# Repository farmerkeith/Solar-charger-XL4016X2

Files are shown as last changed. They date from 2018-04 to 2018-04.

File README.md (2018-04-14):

# Solar-charger-XL4016X2
MPPT Solar charger based on a design by zopinter 
This design uses two commercial DC-DC converter modules based on XL4016, and Arduino Nano for control.
It also has a supplementary input from mains supply controlled from the Nano, and a controlled Load output.
Reverse current flow to the XL4016 converter modules and to the mains supply is prevented by "MOSFET diodes" each consisting of an IRF4905 MOSFET controlled by two BJTs. 
Current flow to and from the battery is monitored, in addition to the solar panel voltage and current and battery voltage essential to the operation of the MPPT algorithm.

# Peripherals
Battery temperature is monitored with a DS18B20 sensor and used to adjust battery set points.
Operational data logging is provided by a micro SD card, with time stamps from a Tiny RTC module using a DS1307 IC. 
An LCD character display provides status information. A push button turns on the backlight of the LCD, saving power when the LCD is not required to be on. 

# Schematic
The schematic circuit diagram has been prepared using KiCad. 

# Layout
A possible layout of the components using Fritzing can be found in the Layout folder. The schematic and PCB parts of the Fritzing files have not been made useful. 

# Software
The software for the Arduino Nano (C++ code) is in the software folder. It still requires change for (at least):
 - pin allocations to correspond to hardware
 - deal with two rather than one XL4016 module
 - data logging and clock
 - testing

See the software code for a full listing of Arduino Nano pin allocations.

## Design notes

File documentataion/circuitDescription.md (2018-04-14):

# Circuit description

Reference: KiCad schematic XL4016X2Single. This is the complete schematic on a single A4 sheet.

# Solar charger circuit
Starting at the top left corner is J1 labelled Solar Panel. The positive and negative wires from the solar panel connect here.

The first component is D3 P6KE47CA which is a transient suppressor diode. Its breakdown voltage is 47 volts. Its purpose is to protect the charger from things like lightning strikes.

Next you find resistors R1, R3 and capacitor C1 (it should be a different label; I will need to change it). The resistors divide the panel voltage down to a level compatible with the Arduino nano, and connect to Arduino pin A0 which does voltage measurement. The voltage range is 5 volts (Arduino Vcc) * (100+15)/15 = 38 Volts, which is enough for a 60-cell solar panel which has an open circuit voltage of 37.8 Volts.

Next you find U2 which is an ACS712 module. It is a Hall effect current sensor. The current from the panel flows in on the P- terminals and out on the P+ terminals. The amount of current affects the voltage on the OUT pin (at the bottom of the module). With zero current the OUT pin sits at Vcc/2, nominally 2.5 Volts. The OUT pin is connected to Arduino A1, which gives a digital measurement of that voltage, and is translated in the software to a current in Amps or milliAmps. The sensitivity of the "5 Amp" module I have specified here is 185 mV per amp, so it can easily measure the maximum current from the solar panel which is 8.7 Amps.

After U2 you find four capacitors C1.1 to C1.4 in parallel. They are there to smooth the current from the panel (which needs to be steady) to the buck converters (which will be of an impulsive nature).

The buck converters U1 and U3 do a DC-DC conversion function. At their output, each converter is rated for 8 Amps, and current limited by internal circuitry to 10 Amps approximately. To achieve good utilisation of your solar panel capacity requires two of these modules added together. They work in parallel. If your panel is at its maximum power point of 31.5 Volts, and the battery is being charged at 12.0 volts with a current of 20 Amps, 10 amps for each of U1 and U3, the input current will be a total of 20*12/31.5=7.6 Amps, or 3.8 Amps per module.  Each of the converters U1 and U3 also has its own smoothing capacitors at the input. I have shown C1.1 to C1.4 because there is a lot of heat generated in these capacitors and putting in some extras is not very expensive and reduces the heating and shoule improve the life time.

The conversion ratio of the two converters U1 and U3 is controlled by PWM signals from the Arduino using pins D9 and D10.

Next is the two MOSFET diode circuits, one for each converter, which then connect the current to the battery via the second ACS712, U4. The main component in each of the two MOSFET diode circuits is the MOSFET, that is Q1 for DC module U1, and Q6 for DC module U3.

The second ACS712 (U4) measures the current both into and out of the battery. Typical situations are current in from the solar panel, and current out to the load. When the mains supply is turned on, it will either decrease the current drawn by the load, or add to the current provided by the solar panels. 

Just to the right of module U4 is the voltage divider for measuring the battery voltage, consisting of resistors R12 and R16 and capacitor C2. The voltage range is 5 volts (Arduino Vcc) * (100+47)/47 = 15.6 Volts, which is enough for a 12 volt lead acid battery. 

Further to the right again is a MP2307 DC-Dc module which draws power from the battery and delivers +5 volts to all the electronic circuits  that require it. 

The last element before the battery connector is a fuse which is there to prevent accidental short circuits causing major component failure. 

# Load control circuit

The load control circuit is in the top right corner of the schematic. It consists of an IRF4905 P-channel MOSFET controlled via a transistor from Arduino pin D4. Pin D4 should be High to turn the load ON, and Low to turn it Off. 

# Mains supply circuit

Mains power comes from a commercial mains adaptor with an output of 12 volts at up to 3 Amps. The adapter is connected via barrel jack J9 which provides a 5.5mm coaxial connection commonly used for mains adapters. These adapters can be sensitive to being fed voltage into them when there is no mains power applied, hence there is a MOSFET diode to prevent that (main component Q9). Mains can be connected or disconnected by Q10 which is controlled via a transistor from Arduino pin D3. 

# Temperature measuring

Battery temperature is measured using DS18B20 U7, connected via a cable through screw terminal J8.

Temperature of the controller is measured using DS18B20 U11 mounted on the TinyRTC real time clock module. 

# Real Time Clock 

In order to be able to accurately time stamp the logged data, a real time clock module is used with a DS1307 and crystal oscillator. The accuracy should be sufficient for this purpose. 

This particular module is also equipped with an EEPROM with 4 kbytes capacity which enables the storage of logging data while the SD card is being unloaded from time to time.

Both the clock and the EEPROM are accessed via the I2C interface from Arduino pins A4 and A5.

# Micro SD card

Data logging is done to a micro SD card which provides ample storage capability for several years of data. Data will be recorded in comma separated text files. Details of the data required and the file duration is to be decided. 

# LCD display

The LCD display will show operational parameters, such as current, voltage and power for the solar panel and the battery, and the operating mode (solar charging; load on or off; mains on or off) 

To see the charactrs in the LCD screen, its back light needs to be turned on. However the back light consumes some power, which is a waste when nobody is there to look at it. Hence we provide a button, so that when somebody wants to see the LCD, they can press the button, and the back light will come on for a set period of time, and then go off again. The time period will be in the software, it could be 15 seconds or a minute, something like that.

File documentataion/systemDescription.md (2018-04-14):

# System Description
# Main functions:
1. Receive energy from a solar panel at a voltage of about 30V and transfer it to a battery at about 12V. 
2. Supply power from the battery to a load consiston of LED floodlights. The LED floodlights should come on when it gets dark in the evening, and turn off either when the next day starts, or if the battery reaches a threshold voltage indicating it has been discharged sufficiently so that further discharge may cause damage. 
3. Switch on a mains supply input at a time close to the end of the day if the battery has not been sufficiently charged during the day as indicated by the charge voltage not reaching a threshold (mains connect threshold). Keep the mains supply connected until the battery reaches a mains disconnect threshold.
4. Perform management of the battery so that it can reach its maximum useful life. This involves: a) boost charge of up to 1 hour per day; b) float charge for the remainder of the day; c) load disconnect threshold to stop further discharge; d) load reconnect threshold to allow reconnection of the load; e) adjustment of voltage thresholds according to the battery temperature.
5. Self protection against transient voltage surges from the solar panel input.
6. Overload protection against excessive temperature.

# Peripheral functions:
7. LCD display of operating values and status (voltages, currents, connections).
8. Data logging of operating values and status to an SD card, with predefined file structure (day files or week files or month files or several?)
9. Real time clock to provide a time stamp to logged data.

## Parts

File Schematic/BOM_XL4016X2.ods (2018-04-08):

 | Bill of Materials for XL4016X2 solar charger project
Sort code | Component | Reference | Value | Cost
1 | Capacitor Electrolytic | C1.1 | 100uF | $0.50
1 | Capacitor Electrolytic | C1.2 | 100uF | $0.50
1 | Capacitor Electrolytic | C1.3 | 100uF | $0.50
1 | Capacitor Electrolytic | C1.4 | 100uF | $0.50
1 | Capacitor Electrolytic | C4 | 10uF | $0.10
2 | Capacitor bypass | C2 | 100nF | $0.10
2 | Capacitor bypass | C3 | 100nF | $0.10
3 | Diode | D1 | 1N4148 | $0.10
3 | Diode | D2 | 1N4148 | $0.10
3 | Diode | D3 | 1N4148 | $0.10
3 | Diode | D4 | 1N4148 | $0.10
3 | Diode | D5 | 1N4148 | $0.10
3 | Diode | D6 | 1N4148 | $0.10
3 | Diode | D7 | 1N4148 | $0.10
3 | Diode | D8 | 1N4148 | $0.10
4 | TVS Diode | D9 | P6KE47CA | $0.10
5 | Fuse | F1 | Fuse_20A | $1.00
6 | Screw terminal 2 | J1 | Solar panel | $0.20
6 | Screw terminal 2 | J2 | Battery | $0.20
6 | Screw terminal 2 | J3 | LOAD | $0.20
6 | Screw terminal 2 | J5 | Buck1_IN | $0.20
6 | Screw terminal 2 | J6 | Buck1_OUT | $0.20
6 | Screw terminal 2 | J7 | Buck2_IN | $0.20
6 | Screw terminal 2 | J8 | Buck2_OUT | $0.20
6 | Screw terminal 3 | J4 | Temperature | $0.30
7 | MOSFET | Q1 | IRF4905 | $0.60
7 | MOSFET | Q12 | IRF4905 | $0.60
7 | MOSFET | Q3 | IRF4905 | $0.60
7 | MOSFET | Q6 | IRF4905 | $0.60
7 | MOSFET | Q9 | IRF4905 | $0.60
8 | BJT NPN | Q13 | 2N3904 | $0.05
8 | BJT NPN | Q2 | 2N3904 | $0.05
8 | BJT PNP | Q10 | 2N3906 | $0.05
8 | BJT PNP | Q11 | 2N3906 | $0.05
8 | BJT PNP | Q4 | 2N3906 | $0.05
8 | BJT PNP | Q5 | 2N3906 | $0.05
8 | BJT PNP | Q7 | 2N3906 | $0.05
8 | BJT PNP | Q8 | 2N3906 | $0.05
10 | Temperature sensor | U5 | DS18B20 | $2.00
11 | Module | U1 | ACS712module | $1.00
11 | Module | U2 | ACS712module | $1.00
11 | Module | U3 | XL4016_DC-DC_module | $5.00
11 | Module | U4 | XL4016_DC-DC_module | $5.00
11 | Module | U6 | ArduinoNano | $4.00
11 | Module | U7 | ESP-01 | $1.50
11 | Module | U9 | MP2307_DC-DC_module | $1.00
11 | Voltage Regulator | U8 | AMS1117-33 | $0.20
12 | Pushbutton | SW1 | Backlight control | $0.10
12 | Display | U10 | LCDSerial2004 | $6.00
21 | Resistor | R16 | 1K | $0.01
21 | Resistor | R13 | 2K2 | $0.01
21 | Resistor | R14 | 2K2 | $0.01
21 | Resistor | R15 | 2K2 | $0.01
22 | Resistor | R19 | 4K7 | $0.01
23 | Resistor | R11 | 10K | $0.01
23 | Resistor | R18 | 10K | $0.01
23 | Resistor | R20 | 10K | $0.01
24 | Resistor | R2 | 15K | $0.01
25 | Resistor | R3 | 22K | $0.01
25 | Resistor | R5 | 22K | $0.01
25 | Resistor | R9 | 22K | $0.01
26 | Resistor | R6 | 47K | $0.01
26 | Resistor | R10 | 47K | $0.01
26 | Resistor | R12 | 47K | $0.01
26 | Resistor | R4 | 47K | $0.01
27 | Resistor | R1 | 100K | $0.01
27 | Resistor | R17 | 100K | $0.01
27 | Resistor | R7 | 100K | $0.01
27 | Resistor | R8 | 100K | $0.01
40 | Wire & hardware
50 | Prototype circuit board |  |  | 2
101 | Barrel jack |  |  | 1
101 | Battery | BT1 | Battery_FLA_+12V_120AH
102 | Mains power converter 12V 3A |  |  | 35
103 | Enclosure
 | Total |  |  | $74.30

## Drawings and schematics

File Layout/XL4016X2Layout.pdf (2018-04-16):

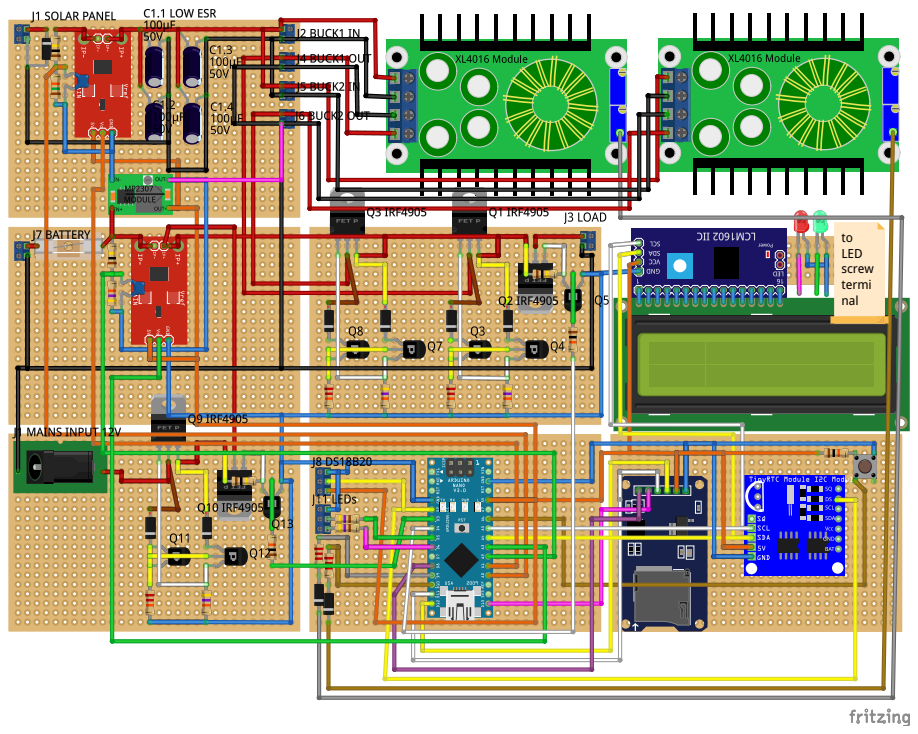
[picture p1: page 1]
to LED screw termi nal

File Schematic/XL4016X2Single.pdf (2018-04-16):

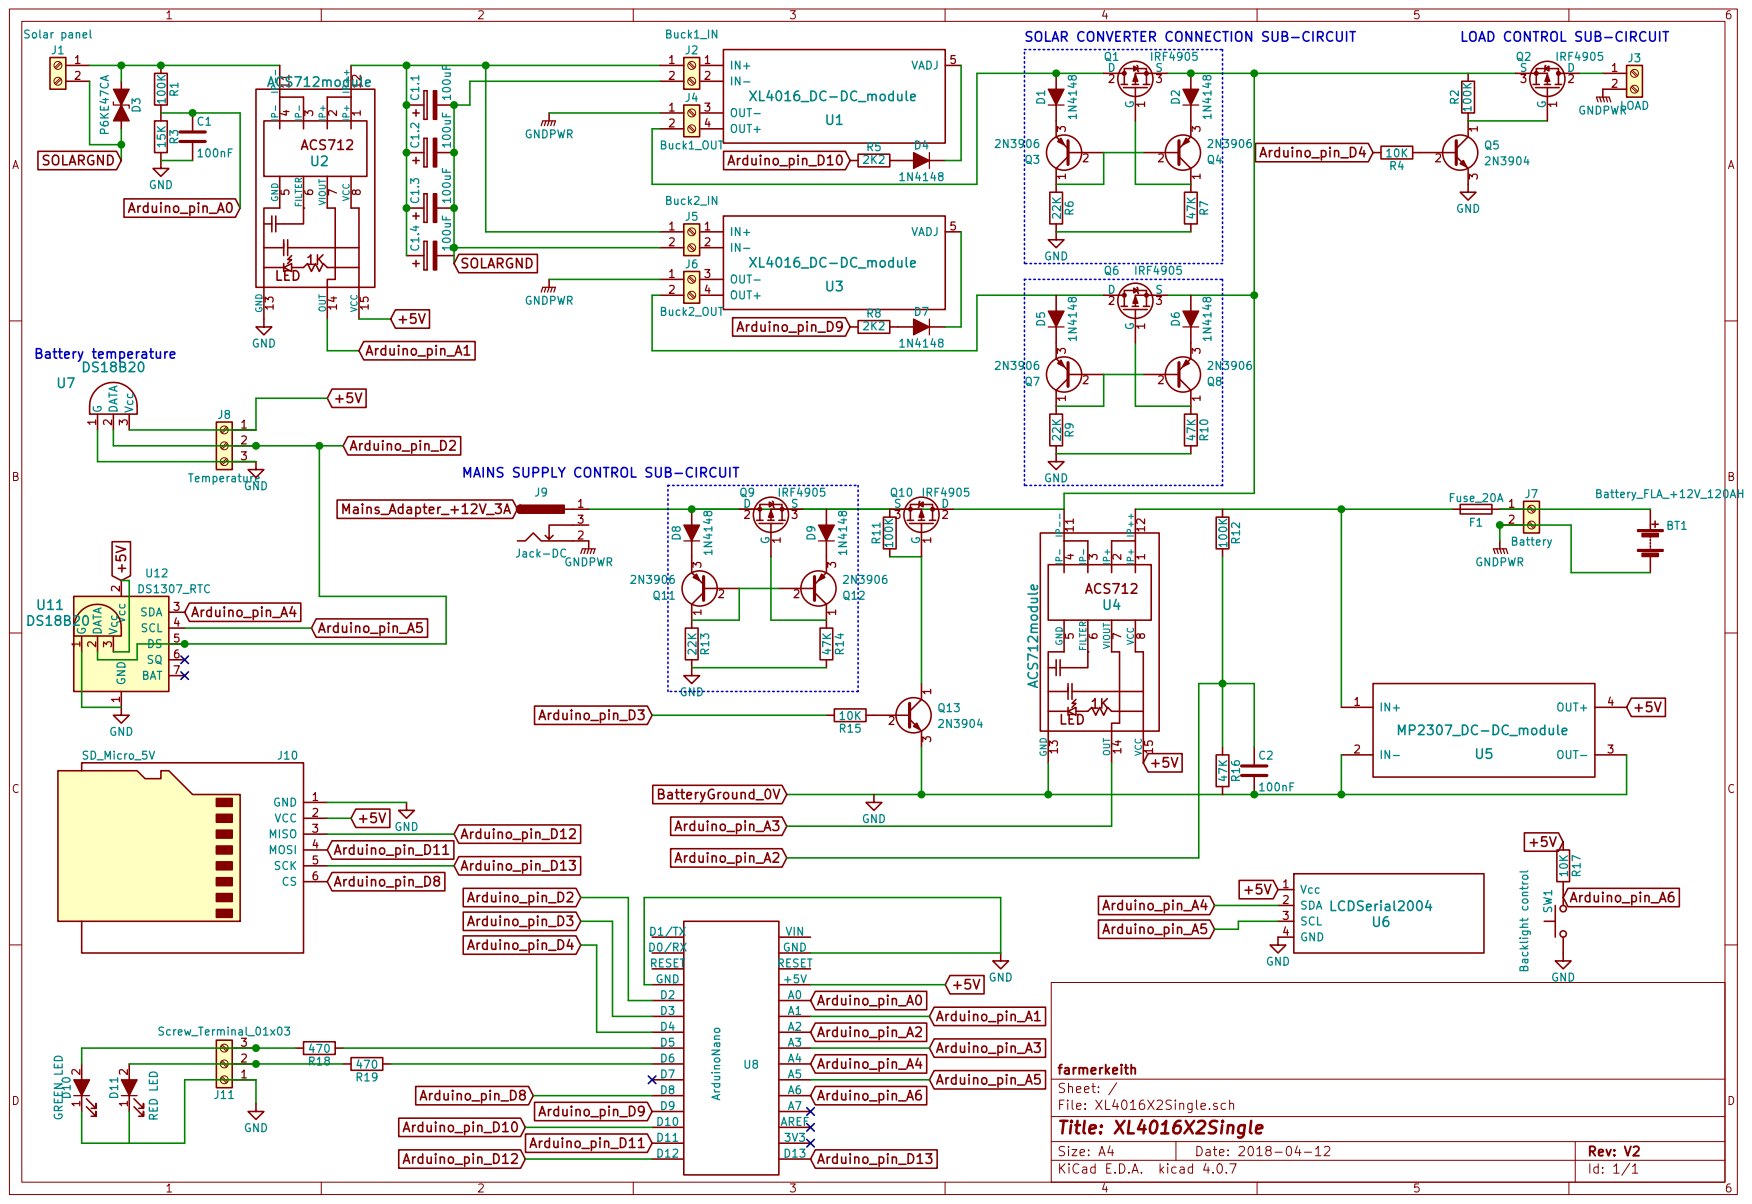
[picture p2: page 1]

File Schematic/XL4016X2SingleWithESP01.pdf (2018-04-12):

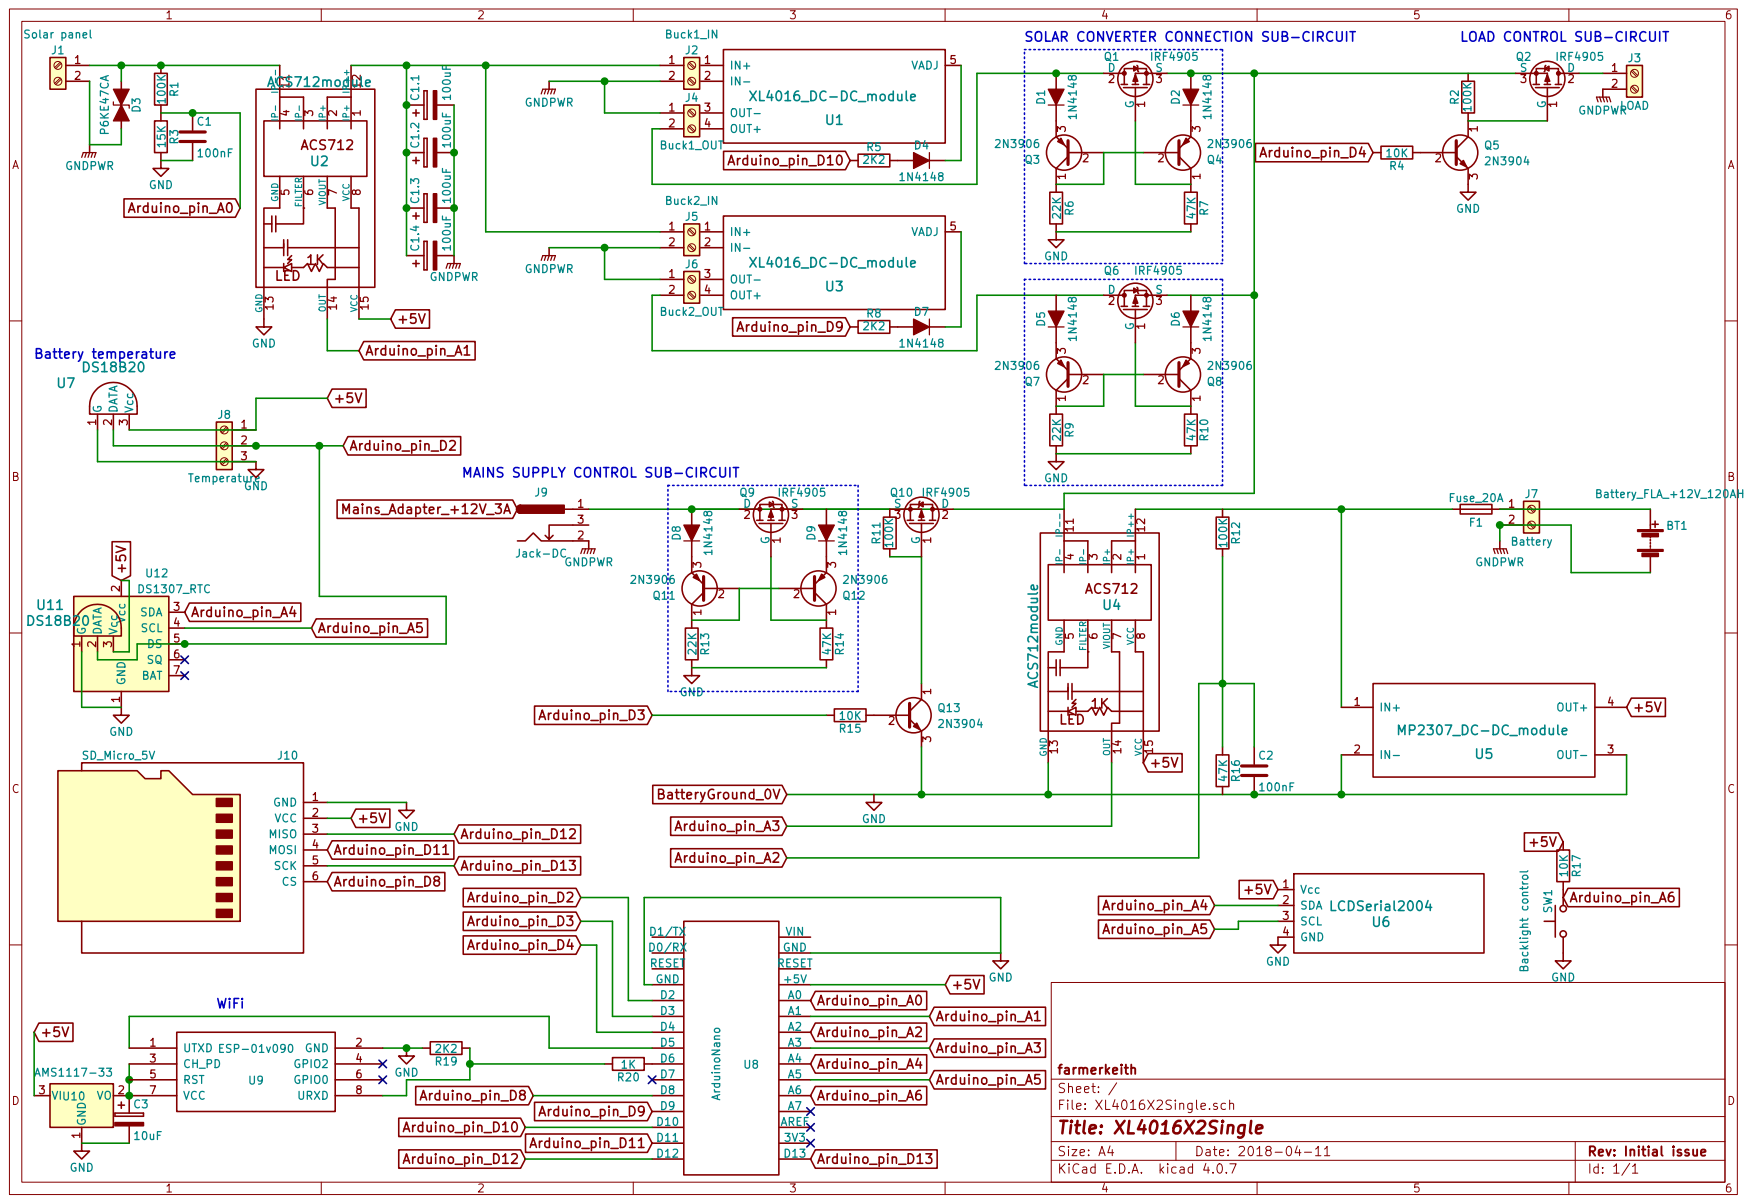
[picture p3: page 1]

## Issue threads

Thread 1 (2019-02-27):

Documentation and working of project

athulsnair, 2019-02-27:
Hello,

      This is not an issue, but I'm interested in doing this project. Where can I find necessary documentation and part list, schematics??

Thanks

farmerkeith, 2019-02-27:
All the documentation that exists can be found under the "code" tab - schematic and some limited documentation.
Depending on your needs, you may find the design using SZBK07 more valuable.
Please also see my Instructable on Controlling DC converter modules for more in-depth information.
https://www.instructables.com/id/Controlling-DC-Converter-Modules/
Keith

Closed 2019-02-27.

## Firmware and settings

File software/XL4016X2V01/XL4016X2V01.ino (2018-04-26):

// software for XL4016X2 solar charger 
// Modified by farmerkeith
// based on version by zopinter
// based on MPPT solar charger Version 3 by deba168
// based on work by Tim Nolan
// modification commenced 13 April 2018
// last change 23 April 2018

// key components:
// Arduino Nano V3 microcontroller
// 2 DC-DC converter modules based on XL4016 with pwm control of output voltage via feedback pin
// XL4016 controlled by the Nano (pwm on D9 and D10)
// solar panel up to 240W Voc<39V Isc<8 Amps
// AGM or flooded lead acid battery nominal 12V
// mains power charge supplement controlled by the Nano (D3)
// LED night time lighting load controlled by the Nano (D4)
// Battery temperature monitored by DS18B20 and used to adjust battery set points (D2)
// LCD display of operational data (I2C on A4, A5)
// LCD backlight controlled by a momentary action push button (A6)
// Micro SD card for data logging (SPI on D11, D12, D13 with CS on D8)
// TinyRTC DC1307 real time clock (I2C on A4, A5)
// Solar controller temperature monitored by DS18B20 mounted on RTC (D2)
// Battery current in and out monitored by ACS712 20A (A3)
// Red and Green status indicators (D5, D6). 

// 2017.01.01: 14938KWh
// Adding HTU21DF sensor
// Adding separate voide for MPPT PO and IC algorith
// Adding EEPROM store
//----------------------------------------------------------------------------------------------------

//////// Arduino pins Connections//////////////////////////////////////////////////////////////////////////////////
// A0 - Solar panel voltage 100K/15K divider
// A1 - Solar panel current ACS 712 5A
// A2 - Battery voltage 100K/47K divider
// A3 - Battery current ACS 712 5A 
// A4 - I2C SDA for LCD, RTC and EEPROM
// A5 - I2C SCL for LCD, RTC and EEPROM
// A6 - Pushbutton for LCD backlight control
// A7 - Spare - use if needed for cooling FAN control 

// D0 - reserved for USB to host
// D1 - reserved for USB to host
// D2 - DS18B20 * 2
// D3 - Mains power control
// D4 - Load control
// D5 - Green LED  
// D6 - Red LED 
// D7 - Spare 
// D8 - CS for SPI to micro SD card
// D9 - PWM control of XL4016 #2
// D10 - PWM control of XL4016 #1
// D11 - SPI MOSI
// D12 - SPI MISO
// D13 - SPI clock SCK; also Nano on board LED

// possible other functions
// COOLING FAN control
// AIR CLEANING FAN control
// ACS712 ENABLE/DISABLE ??

// include libraries ---------------------------------------------------------------------
#include <Wire.h>
#include <LiquidCrystal_I2C.h>
#include <AnalogSmooth.h>
// #include "Adafruit_HTU21DF.h"
#include <EEPROM.h>

// include tab files ---------------------------------------------------------------------
#include "data_recording.h"
#include "LCDcustom_characters.h"

//-----------------------------------------------------------------------------------------------------------------
///////// Hardware connection constants /////////////////////////////////////////////////////////////////////////////////////////////////
//#define BAT_FLOAT 12.35                  // battery voltage we want to stop charging at

const byte SOL_VOLTS_CHAN =0;               // defining the adc channel to read solar volts on A0
const byte SOL_AMPS_CHAN =1;                // Defining the adc channel to read solar amps on A1
const byte BAT_VOLTS_CHAN =2;               // defining the adc channel to read battery volts on A2
const byte BUCK_AMPS_CHAN =3;               // Defining the adc channel to read battery amps on A3
const byte BACK_LIGHT_PIN =6;               // pin A6 is used to control the lcd back light

const byte DS18B20_pin = 2;  // D2 for One-wire to DS18B20 * 2
const byte mains_pin = 3;    // D3 - Mains power control
const byte load_pin = 4;     // D4 - Load control
const byte greenLED_pin =5;  // D5 - Green LED  
const byte redLED_pin = 6;   // D6 - Red LED 
// D7 - Spare 
const byte sd_CS_pin =8;     // D8 - CS for SPI to micro SD card
const byte pwm_buck2 = 9;    // D9 - PWM control of XL4016 #2
const byte pwm_buck1 =10;    // D10 - PWM control of XL4016 #1
// #define PWM_PIN 11

// global constants ----------------------------------------------------------------------
#define wattHours_setup 5983
#define daily_wattHours_setup 0
#define ampHours_setup 0

// #define COOLING_FAN_PWM_PIN 3               // pin used to control air cleaning fan in room
// #define TURN_ON_COOLING_FAN analogWrite(COOLING_FAN_PWM_PIN, 55)
// #define TURN_OFF_COOLING_FAN analogWrite(COOLING_FAN_PWM_PIN, 0)

// #define NIGHT_LIGHT_ENABLE_PIN 7                                             // pin used to control night light
// #define TURN_ON_NIGHT_LIGHT digitalWrite(NIGHT_LIGHT_ENABLE_PIN, HIGH)      // enable Night light
// #define TURN_OFF_NIGHT_LIGHT digitalWrite(NIGHT_LIGHT_ENABLE_PIN, LOW)      // disable Night light

//#define BIG_FAN_PWM_PIN 9                       // pin used to control air cleaning fan in room
//#define TURN_OFF_BIG_FAN analogWrite(BIG_FAN_PWM_PIN, 0)

// #define ACS_ENABLE_PIN 10                                    // pin used to control ACS712 power for energy save purposes
// #define TURN_ON_ACS digitalWrite(ACS_ENABLE_PIN, HIGH)      // enable ACS712 sensors
// #define TURN_OFF_ACS digitalWrite(ACS_ENABLE_PIN, LOW)      // disable ACS712 sensors

#define LED_ON 50                            //milliseconds
#define LED_OFF 5000
unsigned long ms;                          //time from millis()
unsigned long msLast;                      //last time the LED changed state
boolean ledState;                          //current LED state

#define SOL_AMPS_SCALE  0.048828125        // ACS 712 Current Sensor is used. Current Measured = (5/(1024 *0.185))*ADC - (2.5/0.100)
#define BUCK_AMPS_SCALE 0.048828125        // the scaling value for raw adc reading to get solar amps   // 5/(1024*0.100)
#define SOL_VOLTS_SCALE 0.0299        // the scaling value for raw adc reading to get solar volts  // (5/1024)*(R1+R2)/R2 // R1=100k and R2=20k
#define BAT_VOLTS_SCALE 0.0299        // the scaling value for raw adc reading to get battery volts 
#define AVG_NUM 50                          // number of iterations of the adc routine to average the adc readings



//-------------------------------------------- Global variables --------------------------------------------------------
float sol_amps_previous = 0;
float sol_volts_previous = 0;
float buck_amps_previous = 0;


float sol_amps;                       // solar amps
float buck_amps;                      // solar amps

float sol_volts;                      // solar volts
float old_sol_volts = 0;

float bat_volts;                      // battery volts

float sol_watts;                      // solar watts

float buck_watts;                     // buck watts
float rbuck_watts;                    // rounded buck watts

float mppt_track;
float rmppt_track;
float old_mppt_track = 0;

//unsigned int seconds = 0;             // seconds from timer routine
//unsigned int prev_seconds = 0;        // seconds value from previous pass
//unsigned int interrupt_counter = 0;   // counter for 20us interrrupt

int fan_pwm = 0;
int bat_volts_map = 0;                 // for mapping bat volts to fan pwm
int night_light_state = 0;             // variable for storing the load output state (for writing to LCD)

int pwm_value = 0;
int trackDirection = 1;                // step amount to change the value of pulseWidth used by MPPT algorithm

unsigned long ms1 = 0;               // variable to store time the back light control button was pressed in millis
unsigned long ms2 = 0;               // variable to store time the back light control button was pressed in millis
unsigned long ms3 = 0;               // variable to store time the back light control button was pressed in millis
int back_light_pin_State = 0;         // variable for storing the state of the backlight button
int back_light_state = 0;

/*
  float gain;
  int gain_sum = 0;
  int gain_temp = 0;
  int gain_counter = 0;
*/

float eff;                             // efficiency
int eff_sum = 0;
int eff_temp = 0;
int eff_counter = 0;

enum charger_mode {SLEEP, MPPT, FLOAT} charger_state;  // enumerated variable that holds state for charger state machine

float max_sol_watts = 0;              // PZ added
float daily_max_sol_watts = 0;        // PZ added

float max_buck_amps = 0;              // PZ added
float daily_max_buck_amps = 0;        // PZ added

unsigned int msec = 0; // PZ added
int last_msec = 0; // PZ added
int elasped_msec = 0; // PZ added
float elasped_time = 0; // PZ added
float ampSecs = 0; // PZ added
float ampHours = 0; // PZ added
float wattSecs = 0; // PZ added
float wattHours_decimal; // PZ added
float wattHours_temp = 0; // PZ added
float daily_wattHours = 0;
unsigned long wattHours = 0;

LiquidCrystal_I2C lcd(0x27, 2, 1, 0, 4, 5, 6, 7, 3, POSITIVE);  // Set the LCD I2C address

// Adafruit_HTU21DF htu = Adafruit_HTU21DF();

//AnalogSmooth as = AnalogSmooth();
AnalogSmooth as100 = AnalogSmooth(50);


//------------------------------------------------------------------------------------------------------
// This routine is automatically called at powerup/reset
//------------------------------------------------------------------------------------------------------

void setup()                           // run once, when the sketch starts
{
  // recover data from EEPROM
  wattHours = wattHours_setup;
  //  start_wattHours = wattHours_setup;

  ampHours = ampHours_setup;
  daily_wattHours = daily_wattHours_setup;

  TCCR1B = TCCR1B & B11111000 | B00000001;    // set timer 1 (pin 9&10)divisor to 1 for PWM frequency of 31372.55 Hz
  // TCCR2B = TCCR2B & B11111000 | B00000101;    // set timer 2 (pin 3&11) divisor to 1 for PWM frequency of 240 Hz

  DIDR0 = 0x0F;  //Turn off digital input function on ADC channel 0-3, since we will use analogue signals

  Serial.begin(250000);

  pwm_value = 100;
  charger_state = FLOAT;               // start with charger state as sleep

  lcd.begin(20, 4);                    // initialize the lcd for 16 chars 2 lines, turn on backlight
  lcd.noBacklight();                   // turn off the backlight
  back_light_state = 0;
  lcd.createChar(1, solar);            // turn the bitmap into a character
  lcd.createChar(2, battery);          // turn the bitmap into a character
  lcd.createChar(3, _PWM);             // turn the bitmap into a character

//  pinMode(ACS_ENABLE_PIN, OUTPUT);     // sets the digital pin as output
//  TURN_ON_ACS;                         // turn off ACS712

//  pinMode(NIGHT_LIGHT_ENABLE_PIN, OUTPUT);           // output for the LOAD MOSFET (LOW = on, HIGH = off)
//  TURN_OFF_NIGHT_LIGHT;
//  night_light_state = 0;

//  pinMode(BIG_FAN_PWM_PIN, OUTPUT);           // output for the LOAD MOSFET (LOW = on, HIGH = off)

  pinMode (BACK_LIGHT_PIN, INPUT);

  pinMode (pwm_buck1, OUTPUT);
  pinMode (pwm_buck2, OUTPUT);

//  pinMode (COOLING_FAN_PWM_PIN, OUTPUT);

  pinMode(greenLED_pin, OUTPUT);          // sets the digital pin as output
  pinMode(redLED_pin, OUTPUT);            // sets the digital pin as output
}

//------------------------------------------------------------------------------------------------------
// Main loop
//------------------------------------------------------------------------------------------------------
void loop()
{
  read_data();                         // read data from inputs
  mode_select();                       // select the charging state
  set_charger();                       // run the charger state machine
  // print_data();                        // print data
  // cooling_fan();
  // big_fan();
  // night_light();
  // power_save(); // ACS712 uses 10mA at 5V
  keepalive_led();
  lcd_display();                       // lcd display
  // MPPT_test();
  others();                            // max watts and amps;
}

//------------------------------------------------------------------------------------------------------
// This routine reads and averages the analog inputs for this system, solar volts, solar amps and
// battery volts.
//------------------------------------------------------------------------------------------------------
unsigned int read_adc(int channel) {

  unsigned int sum = 0;
  unsigned int temp;
  int i;

  for (i = 0; i < AVG_NUM; i++) {      // loop through reading raw adc values AVG_NUM number of times
    temp = analogRead(channel);        // read the input pin
    sum += temp;                       // store sum for averaging
    delayMicroseconds(100);             // pauses for 50 microseconds
  }
  return (sum / AVG_NUM);              // divide sum by AVG_NUM to get average and return it
}

//------------------------------------------------------------------------------------------------------
// This routine reads all the analog input values for the system. Then it multiplies them by the scale
// factor to get actual value in volts or amps.
//------------------------------------------------------------------------------------------------------
void read_data(void) {
  sol_volts = read_adc(SOL_VOLTS_CHAN) * SOL_VOLTS_SCALE;          // input of solar volts
  //  bat_volts = read_adc(BAT_VOLTS_CHAN) * BAT_VOLTS_SCALE;          // input of battery volts
  bat_volts = as100.analogReadSmooth(BAT_VOLTS_CHAN) * BAT_VOLTS_SCALE;


  if (sol_volts > 9.5) {
    //  TURN_ON_ACS;    // Moved to Power_Save void
    buck_amps = 25.00 - (read_adc(BUCK_AMPS_CHAN) * BUCK_AMPS_SCALE); // input of solar amps
    sol_amps = 25.05 - (read_adc(SOL_AMPS_CHAN) * SOL_AMPS_SCALE);    // input of solar amps
  }
  else {
    //  TURN_OFF_ACS; // Moved to Power_Save void
    sol_amps = 0;
    buck_amps = 0;
  }

  if (charger_state != SLEEP) {
    sol_watts = sol_amps * sol_volts;                               // calculations of solar watts
    buck_watts = buck_amps * bat_volts;

    msec = millis(); // PZ added section
    elasped_msec = msec - last_msec;                                  //Calculate how long has past since last call of this function
    elasped_time = elasped_msec / 1000.0;                             // 1sec=1000 msec
    //  ampSecs = (sol_amps * elasped_time);                              //AmpSecs since last measurement
    ampSecs = (buck_amps * elasped_time);                                //AmpSecs since last measurement
    ampHours = ampHours + ampSecs / 3600;                             // 1 hour=3600sec //Total ampHours since program started
    wattSecs = ampSecs * bat_volts ;                                   //WattSecs since last measurement
    wattHours_decimal = wattSecs / 3600;                          // 1 hour=3600sec //Total wattHours since program started
    wattHours_temp = wattHours_temp + wattHours_decimal;
    daily_wattHours = daily_wattHours + wattHours_decimal;
    last_msec = msec;                                                 //Store 'now' for next time

    if (wattHours_temp >= 1) {
      wattHours++;
      wattHours_temp = wattHours_temp - 1;
    }
  }

  /*
    gain_temp = ((buck_amps - sol_amps) / sol_amps) * 100;
    gain_sum += gain_temp;
    if (gain_counter < 100) (gain_counter = gain_counter + 1);
    else {
      gain_sum = 0;
      gain_counter = 0;
    }
    gain = gain_sum / gain_counter;
    gain = constrain (gain, 0, 99);
  */

  eff_temp = (buck_watts / sol_watts) * 100;
  eff_sum += eff_temp;
  if (eff_counter < 100) (eff_counter = eff_counter + 1);
  else {
    eff_sum = 0;
    eff_counter = 0;
  }
  eff = eff_sum / eff_counter;
  eff = constrain (eff, 0, 99);
}

//------------------------------------------------------------------------------------------------------
// Mode selection routine
//------------------------------------------------------------------------------------------------------
void mode_select() {
  if (sol_volts > bat_volts) { // If battery voltage is in the normal range and there is light on the panel
    if (sol_amps < 0.3) charger_state = FLOAT;                                 // If battery voltage is above 13.5, go into float charging
    else charger_state = MPPT;                                                                 // If battery voltage is less than 13.5, go into bulk charging
  }
  else  {                                                        // If there's no light on the panel, go to sleep
    charger_state = SLEEP;
  }
}

void set_charger(void) {

  switch (charger_state) {                                                                    // skip to the state that is currently set

    case SLEEP:                                                                               // the charger is in the sleep state
      if (pwm_value > 0) pwm_value--;
      pwm_value = constrain (pwm_value, 0, 255);
      analogWrite (pwm_buck1, pwm_value);
      analogWrite (pwm_buck2, pwm_value);
      break;

    case MPPT:                                                                                // the charger is in the bulk state
      if (sol_volts >= 18.00)
      {
        pwm_value--;
        analogWrite (pwm_buck1, pwm_value);
        analogWrite (pwm_buck2, pwm_value);
      }
      else if (sol_volts < 14.00)
      {
        pwm_value++;
        analogWrite (pwm_buck1, pwm_value);
        analogWrite (pwm_buck2, pwm_value);
      }
      else {
        MPPT_PO();
        //MPPT_IC();
      }
      break;

    case FLOAT:                                                                               // the charger is in the float state, it uses PWM instead of MPPT
      if (pwm_value > 0) pwm_value--;
      pwm_value = constrain (pwm_value, 0, 255);
      analogWrite (pwm_buck1, pwm_value);
      analogWrite (pwm_buck2, pwm_value);
      delay (75);
      break;

    default:                                                                                  // if none of the other cases are satisfied,
      analogWrite (pwm_buck1, 0);
      analogWrite (pwm_buck2, 0);
      break;
  }
}

void MPPT_PO (void) {
  rmppt_track = round (buck_amps * sol_volts * 10) ;                  // calculations of hybrid watts
  //  rmppt_track = round (sol_watts * 10);
  mppt_track = rmppt_track / 10 ;


  if ((mppt_track < old_mppt_track) || (pwm_value <= 0) || (pwm_value >= 255)) {
    trackDirection = -trackDirection;                 // if pulseWidth has hit one of the ends reverse the track direction
    pwm_value = pwm_value + trackDirection;           // add (or subtract) track Direction to(from) pulseWidth
  }
  else pwm_value = pwm_value + trackDirection;


  old_mppt_track = mppt_track;

  pwm_value = constrain (pwm_value, 0, 255);
  analogWrite (pwm_buck1, pwm_value);
  analogWrite (pwm_buck2, pwm_value);
  delay (75);
}

void MPPT_IC (void) {
  float dV = sol_volts - sol_volts_previous;
  float dI = sol_amps - sol_amps_previous;

  if (dV == 0)
  { if (dI == 0)
    {
      sol_volts = sol_volts;
      sol_amps = sol_amps;
      //delay(1000);
    }

    else if (dI > 0) // that means you have to make dI=0 decrease I,decraese duty cycle
    {
      pwm_value++;
      analogWrite (pwm_buck1, pwm_value);
      analogWrite (pwm_buck2, pwm_value);
    }

    else if (dI < 0) // that means you have to increase I to make dI=0;increase duty cycle
    {
      pwm_value--;
      analogWrite (pwm_buck1, pwm_value);
      analogWrite (pwm_buck2, pwm_value);
    }
  }

  else
  {
    if (dI / dV + (sol_amps / sol_volts) <= 0.001)
    {
      sol_volts = sol_volts;
      sol_amps = sol_amps;
      //delay(1000);
    }

    else if (dI / dV < -(sol_amps / sol_volts))
    {
      pwm_value--;
      analogWrite (pwm_buck1, pwm_value);
      analogWrite (pwm_buck2, pwm_value);
    }
    else
    {
      pwm_value++;
      analogWrite (pwm_buck1, pwm_value);
      analogWrite (pwm_buck2, pwm_value);
    }
  }
  sol_volts_previous = sol_volts;
  sol_amps_previous = sol_amps;
  delay(75);
}

//------------------------------------------------------------------------------------------------------
// This routine prints all the data out to the serial port.
//------------------------------------------------------------------------------------------------------
void print_data (void) {

  Serial.print(bat_volts_map);
  Serial.print("    ");

  Serial.print("Fan_pwm= ");
  Serial.print(fan_pwm);
  Serial.print("    ");

  Serial.print("P= ");
  Serial.print(sol_watts, 1);
  Serial.print("    ");

  Serial.print("I_s= ");
  Serial.print(sol_amps);
  Serial.print("    ");

  Serial.print("I_b= ");
  Serial.print(buck_amps);
  Serial.print("    ");

  Serial.print("V_s= ");
  Serial.print(sol_volts);
  Serial.print("    ");

  Serial.print("V_b= ");
  Serial.print(bat_volts);
  Serial.print("    ");

  if (charger_state == SLEEP) Serial.print("SLEEP");
  else if (charger_state == MPPT) Serial.print("MPPT ");
  else if (charger_state == FLOAT) Serial.print("FLOAT");
  Serial.print("    ");

  Serial.print("Track_W: ");
  Serial.print(mppt_track);
  Serial.print("  >>  ");

  Serial.print("pwm = ");
  Serial.print(pwm_value);
  Serial.print("    ");

  Serial.print("Ef=");
  Serial.print(eff, 0);
  Serial.print("%   ");

  /*  Serial.print("Gain=");
    Serial.print(gain, 0);
    Serial.print("%   ");
  */
  Serial.print("\n\r");
}
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

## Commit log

2018-04-06 Initial creation of repository with schematic
    [ChargerModule.sch, ConnectModule.sch, ControlModule.sch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]
2018-04-06 Added TVS diode to connect module
    [ConnectModule.sch]
2018-04-08 added BOM, started Fritzing prototype diagram, minor layout changes in KiCad
    [BOM_XL4016X2.ods, ConnectModule.sch, ControlModule.sch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]
2018-04-08 minor text changes
    [LoadControlModule.sch]
2018-04-11 Minor corrections. Combined 3 sheets into a single schematic
    [ControlModule.sch, LoadControlModule.sch, XL4016X2Single.kicad_pcb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]
2018-04-11 minor fixes to shematic; progressed Fritzing but not finished yet
    [XL4016X2.fzz, XL4016X2Single.sch]
2018-04-12 added SD and RTC modules
    [XL4016X2Single.sch]
2018-04-12 deleted ESP-01 (WiFi) module
    [XL4016X2Single.sch]
2018-04-12 added mains input and Nano to Fritzing
    [XL4016X2.fzz, _saved_XL4016X2Single.sch]
2018-04-12 added RTC and SD to Fritzing. Minor updates to KiCad schematic.
    [XL4016X2.fzz, XL4016X2Single.sch, _saved_XL4016X2Single.sch]
2018-04-12 Fritzing layout updated with XL4016 modules
    [XL4016X2.fzz]
2018-04-13 added control lines for XL4016 modules
    [XL4016X2.fzz]
2018-04-13 added LCD and backlight control button
    [XL4016X2.fzz]
2018-04-14 updated readme, added system description and circuit description in documentation folder
2018-04-16 Green and Red status LEDs added
    [XL4016X2.fzz, XL4016X2Single.sch]
2018-04-16 removed schematic on multiple sheets
    [ChargerModule.sch, ConnectModule.sch, ControlModule.sch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]
2018-04-26 software pins aligned with hardware
    [XL4016X2.fzz]
